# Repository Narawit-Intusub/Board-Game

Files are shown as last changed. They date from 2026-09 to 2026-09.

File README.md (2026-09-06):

# Modular Smart LED Matrix (กระดานไฟ LED อัจฉริยะต่อขยายได้อิสระสำหรับระบบเกมกระดาน)

---

## 1. ภาพรวมโปรเจกต์ (Project Overview)

**Modular Smart LED Matrix** คือ กระดานแสดงผลไฟ LED อัจฉริยะแบบต่อขยายได้อิสระ (Modular Interactive Tabletop Gaming Grid) ออกแบบมาเพื่อเป็นกระดานเล่นเกมแบบ Interactive ร่วมกับเอนจินเกม (เช่น Unity หรือ PC) และหน้าจอแสดงผลกราฟิกแบบปรับเปลี่ยนรูปทรงได้อย่างอิสระ

ระบบถูกออกแบบภายใต้สถาปัตยกรรม **Smart Tile (Distributed Grid Architecture)** โดยแต่ละแผ่นกระดานมีขนาด **$192.0 \times 192.0\text{ mm}$ ($19.2 \times 19.2\text{ cm}$)** แบ่งเป็น **16 ช่องตาราง ($4 \times 4$ Cells ช่องละ $48.0 \times 48.0\text{ mm}$)** แต่ละช่องมีไฟ 4 หลอด (รวม 64 หลอดต่อแผ่น) ขับแสดงผลเฉพาะในบอร์ดตัวเองอย่างอิสระ ไม่ต่อสายไฟ LED เป็นโซ่อนุกรมข้ามบอร์ด

```text
Unity / PC
    │
    │ USB DATA
    ▼
┌───────────────────────────────┐
│ MASTER                        │
│                               │
│ ESP32 Gateway                 │
│    │ Internal UART            │
│    ▼                          │
│ ATtiny1604 Tile Controller    │
│    ├── LED Matrix ของ Master  │
│    └── Magnetic Bus N/E/S     │
└───────────────┬───────────────┘
                │
        VBUS, TX, RX, GND
                │
       ┌────────┴────────┐
       ▼                 ▼
┌─────────────┐   ┌─────────────┐
│ Slave Tile  │   │ Slave Tile  │
│ ATtiny1604  │   │ ATtiny1604  │
└─────────────┘   └─────────────┘
```

---

## 2. โครงสร้างระบบ (System Structure)

ชุดต้นแบบประกอบด้วยกระดานทั้งหมด 4 แผ่น:

| บอร์ด | ตัวควบคุม | หน้าที่หลัก |
| :--- | :--- | :--- |
| **Master (1 แผ่น)** | **ESP32 Wemos D1 Mini + ATtiny1604** | • **ESP32:** เกตเวย์เชื่อม Unity ผ่าน USB, เก็บ Topology ทั้งระบบ, คำนวณ Global Grid, แยก Packet ตาม Tile ID, ตรวจสอบสถานะระบบ<br>• **ATtiny1604:** ควบคุม Tile ของ Master, ขับ 64 LEDs, จัดการ Magnetic Bus N/E/S |
| **Slave 1 (1 แผ่น)** | **ATtiny1604** | ขับ LED 64 ดวงในตัว, รับ-ส่งต่อ Packet, ตรวจจับเพื่อนบ้าน |
| **Slave 2 (1 แผ่น)** | **ATtiny1604** | ขับ LED 64 ดวงในตัว, รับ-ส่งต่อ Packet, ตรวจจับเพื่อนบ้าน |
| **Slave 3 (1 แผ่น)** | **ATtiny1604** | ขับ LED 64 ดวงในตัว, รับ-ส่งต่อ Packet, ตรวจจับเพื่อนบ้าน |

### สรุปรวมอุปกรณ์หลักของระบบ:
* **ESP32:** จำนวน 1 ตัว (อยู่บนบอร์ด Master เท่านั้น ทำหน้าที่ Gateway ระดับระบบ)
* **ATtiny1604:** จำนวน 4 ตัว (ประจำทุกแผ่น แผ่นละ 1 ตัว ทำหน้าที่ Tile Controller มาตรฐานเดียวกัน)
* **USB Data:** ต่อคอมพิวเตอร์เฉพาะบอร์ด Master เพียงจุดเดียว
* **Power Input:** จ่ายไฟเข้าที่บอร์ด Master เพียงจุดเดียว แล้วส่งผ่านบัส `VBUS` ไปยังแต่ละแผ่น

---

## 3. หน้าที่ของแต่ละตัวควบคุม

### 3.1 หน้าที่ของ ESP32 (System Gateway)
* ติดต่อกับ Unity ผ่านสาย USB เพียงเส้นเดียว
* รับสถานะเกม ข้อมูลสีพิกัด และคำสั่งเฟรมภาพ
* บันทึกและวิเคราะห์โครงสร้างแผนผังทั้งหมดของระบบ (System Topology)
* คำนวณตำแหน่งสัมพัทธ์และการหมุนของแต่ละ Tile รวมเป็น Global Grid ผืนเดียว
* แยกข้อมูล Packet ตาม Tile ID
* ตรวจสอบสถานะและรายงานความผิดปกติของระบบ
* **ส่ง Packet ทั้งหมดให้ ATtiny1604 ของ Master ผ่าน Internal UART**
* *ESP32 ไม่ต้องต่อเข้าหัวแม่เหล็กภายนอกโดยตรง และไม่ต้องขับ LED โดยตรง*

### 3.2 หน้าที่ของ ATtiny1604 (Tile Controller ประจำทุกแผ่น รวม 4 ตัว)
* มีรหัส **Tile ID** ประจำตัว
* ขับไฟ LED ภายในแผ่นตัวเอง (64 LEDs จากข้อมูลสี 16 ช่อง)
* จัดการหน่วยความจำสี 16 ช่อง (Active Buffer และ Back Buffer)
* รับและส่งต่อ Packet ข้อมูลตามเส้นทางเครือข่าย
* ส่งข้อความ `HELLO` เพื่อค้นหาเพื่อนบ้าน
* **ตรวจจับเพื่อนบ้านและทิศทางการเชื่อมต่อเมื่อได้รับข้อความ `HELLO` ทางขา RX แยกแต่ละทิศ (`LINK_RX_N/E/S/W`)**
* รอรับสัญญาณแสดงผลพร้อมกัน (`FRAME_COMMIT`)
* รายงานสถานะกลับไปยัง ESP32 ผ่านโครงข่ายบัส
* **ATtiny บน Master และ Slave ใช้ Firmware สถาปัตยกรรมพื้นฐานชุดเดียวกัน**

---

## 4. บัสแม่เหล็ก 4 จุด (4-Pin Magnetic Link)

แต่ละขอบที่เชื่อมต่อระหว่างบอร์ดมีพินสัญญาณ 4 พิน:

$$\text{[ VBUS ]} \quad \vert \quad \text{[ LINK_TX ]} \quad \vert \quad \text{[ LINK_RX ]} \quad \vert \quad \text{[ GND ]}$$

```text
  Female Connector (North / East)       Male Connector (South / West)
      +---------------------+               +---------------------+
      | (1)  (2)  (3)  (4)  |               | (1)  (2)  (3)  (4)  |
      | VBUS LinkTX LinkRX GND|             | GND LinkTX LinkRX VBUS|
      +---------------------+               +---------------------+
```

### 4.1 การจับคู่เมื่อประกบบอร์ด (Poka-Yoke 180° Inversion):
เมื่อนำขอบ Female ประกบกับขอบ Male หลังหมุน 180° พินจะจับคู่ตรงกันอย่างถูกต้อง:
* $\text{Pin 1 (VBUS)} \longleftrightarrow \text{Pin 4 (VBUS)}$: บัสไฟเลี้ยงหลัก
* $\text{Pin 2 (LINK_TX)} \longleftrightarrow \text{Pin 3 (LINK_RX)}$: สายส่งข้อมูลชนสายรับข้อมูล
* $\text{Pin 3 (LINK_RX)} \longleftrightarrow \text{Pin 2 (LINK_TX)}$: สายรับข้อมูลชนสายส่งข้อมูล
* $\text{Pin 4 (GND)} \longleftrightarrow \text{Pin 1 (GND)}$: ระนาบกราวด์ร่วม

### 4.2 ทิศทางขั้วต่อในแต่ละบอร์ด:
* **Master มี 3 ทิศ:** **North, East, South** (เว้นด้าน **West** ไว้สำหรับช่องรับไฟหลักและพอร์ต USB สื่อสารกับคอมพิวเตอร์)
* **Slave มีครบ 4 ทิศ:** **North, East, South, West**

### 4.3 สถาปัตยกรรมการรับ-ส่งสัญญาณ (Directional RX & Shared TX):
บนแต่ละ Tile:
* มีขา **LINK_RX แยกอิสระ 4 ทิศทาง:** `LINK_RX_N`, `LINK_RX_E`, `LINK_RX_S`, `LINK_RX_W` ทำให้ระบุทิศทางของแพ็กเก็ตที่ส่งเข้ามาได้อย่างแม่นยำ
* มีขา **LINK_TX หนึ่งเส้นใช้ร่วมกันทุกด้าน:** เมื่อ Tile สั่งส่งข้อมูล ข้อมูลจะบรอดคาสต์ออกไปยังเพื่อนบ้านทุกด้านพร้อมกัน

---

## 5. รูปแบบแพ็กเก็ตและการป้องกันข้อมูลวนซ้ำ (Packet Architecture & Loop Prevention)

เนื่องจากขา `LINK_TX` เป็นสายร่วมที่กระจายสัญญาณออกทุกด้านพร้อมกัน Packet จึงต้องมีโครงสร้างข้อมูลกำกับ:

```text
+-----------+----------------+-----------------+--------------+-----+-----+--------+
| Source ID | Destination ID | Sequence Number | Frame Number | TTL | CRC | Data.. |
+-----------+----------------+-----------------+--------------+-----+-----+--------+
```

* **Source ID / Destination ID:** ระบุโหนดต้นทางและปลายทาง (หรือ Broadcast ID)
* **Sequence Number:** ลำดับของแพ็กเก็ต
* **Frame Number:** เลขเฟรมภาพสำหรับการซิงก์แสดงผล
* **TTL (Time-To-Live):** ลดค่าลงทีละ 1 ทุกครั้งที่ส่งต่อ เพื่อตัดวงจรแพ็กเก็ตตกค้าง
* **CRC:** ตรวจสอบความถูกต้องของข้อมูล
* **การป้องกันข้อมูลวนซ้ำ (Deduplication):** แต่ละ Tile จะจดจำ Sequence Number ล่าสุด และ**ไม่ประมวลผลแพ็กเก็ตเดิมซ้ำ** ช่วยป้องกันปัญหาข้อมูลวนลูปในกรณีที่มีเส้นทางเชื่อมต่อหลายทาง

---

## 6. เส้นทางข้อมูลที่ถูกต้อง (Data Flow Pipeline)

```text
Unity
  └──► ESP32 (Master)
         └──► ATtiny1604 (Master)
                ├──► ขับไฟ LED 64 ดวงบน Master
                └──► Magnetic Link (LINK_TX)
                       └──► ATtiny1604 (Slave Tile)
                              ├──► ขับไฟ LED 64 ดวงบน Slave
                              └──► ส่งต่อไปยัง Slave ถัดไป
```

* **Master Tile:** Unity $\rightarrow$ ESP32 $\rightarrow$ ATtiny Master $\rightarrow$ LED Master
* **Slave Tiles:** Unity $\rightarrow$ ESP32 $\rightarrow$ ATtiny Master $\rightarrow$ Magnetic Link $\rightarrow$ ATtiny Slave $\rightarrow$ ส่งต่อไปยัง Slave ถัดไป
* **ESP32 ไม่ส่งข้าม ATtiny Master ไปยังบอร์ดลูกโดยตรง**

---

## 7. สถาปัตยกรรมระบบไฟ (Power Architecture)

หลักการจ่ายไฟของระบบกำหนดไว้ดังนี้:

```text
Power Input
   └──► Master Protection
          └──► VBUS (ส่งผ่านขั้วต่อแม่เหล็กไปยังทุกแผ่น)
                 └──► Local Power Converter ในแต่ละ Tile
                        └──► 5V คงที่สำหรับขับ LED และเลี้ยง ATtiny1604
```

> [!IMPORTANT]
> **ข้อกำหนดในการออกแบบภาคจ่ายไฟ:**
> 1. **ใช้ชื่อบัสกลางว่า `VBUS`:** ไม่ส่งตรง 5V ผ่านทุกบอร์ดในระยะยาว เพื่อรองรับการจ่ายแรงดันที่สูงขึ้น (เช่น 9V–12V) แล้วใช้ Local Step-Down Converter ลดเป็น 5V ภายในแต่ละแผ่น เพื่อลดแรงดันตกคร่อม (Voltage Drop) และลดกระแสบนพินแม่เหล็ก
> 2. **ยังไม่ล็อกเบอร์อุปกรณ์และแรงดัน VBUS ในสเปกหลัก:** รายละเอียดของแรงดัน VBUS, ชนิดคอนเนคเตอร์ไฟเข้า, ชนิดวงจรแปลงไฟ, อุปกรณ์วัดกระแส, และพิกัด TVS (ห้ามล็อก SMAJ5.0A หาก VBUS มีโอกาสสูงกว่า 5V) จะสรุปหลังจากการทดสอบพิกัดกระแสจริงของหัวแม่เหล็กและกำลังวัตต์สูงสุดของ LED ทั้งระบบ
> 3. **ตัวต้านทาน CC 5.1kΩ:** ทำหน้าที่ระบุสถานะ Sink บนพอร์ต USB Type-C พื้นฐานเท่านั้น ไม่ได้รับรองการจ่ายกระแส 5V/3A และไม่ใช่ระบบเจรจาแรงดัน USB-PD

---

## 8. การจัดการระดับแรงดันสัญญาณ (Logic Level Translation)

* **หาก ATtiny1604 เลี้ยงด้วยไฟ 5V:** สัญญาณ GPIO เอาต์พุต (รวมถึงขาขับ LED `LED_DATA`) จะมีระดับแรงดันเป็น 5V CMOS Logic อยู่แล้ว จึงสามารถขับขา DIN ของโมดูล WS2812B ได้โดยตรงโดยไม่ต้องใช้ Level Shifter 3.3V$\rightarrow$5V หน้า LED
* **จุดที่ต้องแปลงระดับแรงดัน (Level Shifting):** คือส่วนเชื่อมต่อระหว่าง **ESP32 (แรงดันสัญญาณ 3.3V)** กับ **ATtiny1604 (แรงดันสัญญาณ 5V)** บนบอร์ด Master เพื่อให้การส่งข้อมูล UART ภายในทำงานได้อย่างถูกต้องและปลอดภัย

---

## 9. เอกสารอ้างอิงเฉพาะบอร์ด (Detailed Documentation Links)

* 📖 **[เอกสารวงจรและฮาร์ดแวร์บอร์ดแม่ (Master Controller Board README)](hardware/master/README.md)**
* 📖 **[เอกสารวงจรและฮาร์ดแวร์บอร์ดลูก (Slave Expansion Board README)](hardware/slave/README.md)**

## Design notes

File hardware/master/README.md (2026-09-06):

# Master Controller Board (บอร์ดแม่) - Dual-MCU Smart Tile (ESP32 + ATtiny1604)

เอกสารนี้อธิบายรายละเอียดการออกแบบทางฮาร์ดแวร์ บล็อกการทำงาน หน้าที่ของแต่ละโมดูล และโครงสร้างทางวิศวกรรมของ **Master Controller Board** (ไฟล์ KiCad: [Master_Matrix_4x4.kicad_sch](Master_Matrix_4x4.kicad_sch), [Master_Matrix_4x4.kicad_pcb](Master_Matrix_4x4.kicad_pcb)) ภายใต้สถาปัตยกรรม **Dual-MCU Smart Tile Grid**

---

## 1. ภาพรวมบอร์ดแม่ (Master Board Overview)

**Master Controller Board** ขนาดแผ่น **$192.0 \times 192.0\text{ mm}$ ($19.2 \times 19.2\text{ cm}$)** แบ่งเป็น **16 ช่องตาราง ($4 \times 4$ Cells ช่องละ $48.0 \times 48.0\text{ mm}$)** แต่ละช่องติดตั้งไฟ LED 4 ดวงแบบ $2 \times 2$ (รวม 64 หลอด) ทำหน้าที่เป็นทั้ง **พื้นที่เล่นในตัว** และ **เกตเวย์เชื่อมต่อกับคอมพิวเตอร์/Unity**

### สถาปัตยกรรมชิปคู่บนบอร์ดแม่ (Dual-MCU Architecture):
บอร์ดแม่รวมไมโครคอนโทรลเลอร์ 2 ตัวไว้บนแผ่นเดียว เพื่อแยกบทบาทหน้าที่อย่างชัดเจน:

1. **ESP32 Gateway (`U1`):**
   - เชื่อมต่อกับ Unity / PC ผ่านสาย USB ทางขอบด้านซ้าย (West)
   - รับข้อมูลเกม, สถานะ, ข้อมูลสี และค่าความสว่างจาก Unity
   - เก็บโครงสร้างแผนผังความสัมพันธ์ทั้งระบบ (System Topology Map)
   - คำนวณ Global Grid และแปลงพิกัดสากล
   - แยกข้อมูล Packet ตาม Tile ID
   - ตรวจสอบสถานะการทำงานของระบบ
   - **ส่งทุก Packet ให้ ATtiny1604 ของบอร์ดแม่ผ่าน Internal UART**
   - *ESP32 ไม่ต่อเข้าหัวแม่เหล็กภายนอกโดยตรง และไม่ขับ LED โดยตรง*

2. **ATtiny1604 Master Tile Controller (`U_ATTINY`):**
   - ทำหน้าที่เป็น Smart Tile ประจำบอร์ดแม่ โดยใช้ **Firmware สถาปัตยกรรมเดียวกับบอร์ดลูก**
   - รับ Packet ข้อมูลจาก ESP32
   - จัดการเก็บสี 16 ช่องในหน่วยความจำ (Active Buffer และ Back Buffer)
   - ขับไฟ LED 64 ดวงในบอร์ดตัวเอง (1 สี ขยายออกเป็น 4 หลอดต่อช่อง)
   - ขับสัญญาณออกสู่โครงข่ายแม่เหล็ก 3 ทิศทาง (**North, East, South**) ผ่านสาย `LINK_TX`
   - กระจายสัญญาณและส่งต่อแพ็กเก็ตไปยังบอร์ดลูก

```text
Unity Game Engine
       │ USB DATA
       ▼
+-------------------------------------------------------------------------+
|                        Master Controller Board                          |
|                                                                         |
|                     [ J_NORTH (Female Mag-4P) ]                         |
|                     (VBUS, Link TX, Link RX, GND)                       |
|                                  ^                                      |
|                                  |                                      |
|  [ POWER INPUT ]            +----+----+                                 |
|  [ USB TO UNITY ]           | ATtiny  | <---> [ J_EAST (Female) ]       |
|         │                   |  1604   |       (VBUS, TX, RX, GND)       |
|         ▼                   | Master  |                                 |
|   +-----------+  Internal   +----+----+                                 |
|   |   ESP32   |  UART            | DIN_LOCAL (5V Logic)                 |
|   |  Gateway  | ---------->      v                                      |
|   +-----------+ (Level Shift)+---------------+                          |
|         │                    |  LED Matrix   | (MOD1 -> MOD2 -> .. MOD16|
|  (System Mgmt)               |  (64 LEDs)    | (Local Driving Only)     |
|   (West Edge)                +---------------+                          |
|                                  |                                      |
|                                  v                                      |
|                     [ J_SOUTH (Male Mag-4P) ]                           |
|                     (VBUS, Link TX, Link RX, GND)                       |
+-------------------------------------------------------------------------+
```

---

## 2. ขั้วต่อแม่เหล็ก 3 ทิศทาง (3-Edge Magnetic Link Bus)

บอร์ด Master ติดตั้งขั้วต่อแม่เหล็กที่ขอบบอร์ด **3 ด้านเท่านั้น** ได้แก่ **North, East, South** (เว้นด้าน **West** ไว้สำหรับช่องรับไฟหลักและพอร์ต USB เชื่อมต่อคอมพิวเตอร์):

$$\text{Pin 1: [ VBUS ]} \quad \vert \quad \text{Pin 2: [ LINK_TX ]} \quad \vert \quad \text{Pin 3: [ LINK_RX ]} \quad \vert \quad \text{Pin 4: [ GND ]}$$

```text
  Female Connector (North / East)       Male Connector (South)
      +---------------------+               +---------------------+
      | (1)  (2)  (3)  (4)  |               | (1)  (2)  (3)  (4)  |
      | VBUS LinkTX LinkRX GND|             | GND LinkTX LinkRX VBUS|
      +---------------------+               +---------------------+
```

### การจับคู่สัญญาณเมื่อประกบกัน (Poka-Yoke 180° Inversion):
* **Pin 1 (VBUS) $\longleftrightarrow$ Pin 4 (VBUS):** บัสจ่ายไฟเลี้ยงหลักของโครงข่าย
* **Pin 2 (LINK_TX) $\longleftrightarrow$ Pin 3 (LINK_RX):** สายส่งข้อมูลชนสายรับข้อมูลของเพื่อนบ้าน
* **Pin 3 (LINK_RX) $\longleftrightarrow$ Pin 2 (LINK_TX):** สายรับข้อมูลชนสายส่งข้อมูลของเพื่อนบ้าน
* **Pin 4 (GND) $\longleftrightarrow$ Pin 1 (GND):** ระนาบกราวด์ร่วมของทั้งระบบ

---

## 3. เส้นทางข้อมูลและการกระจายสัญญาณ (Data Routing & Level Shifting)

1. **เส้นทางข้อมูล:**
   * Unity $\rightarrow$ ESP32 (ถอดรหัสและแยก Packet)
   * ESP32 $\rightarrow$ ATtiny Master (ผ่าน Internal UART)
   * ATtiny Master $\rightarrow$ ขับไฟ LED 64 ดวงบนบอร์ด Master
   * ATtiny Master $\rightarrow$ กระจายข้อมูลออกสู่ `LINK_TX` ขั้วต่อแม่เหล็ก N/E/S ไปยังบอร์ดลูก
2. **การแปลงระดับแรงดัน (Level Shifting):**
   * หาก ATtiny1604 ทำงานที่แรงดัน 5V เอาต์พุต GPIO ของ ATtiny จะเป็น 5V Logic อยู่แล้ว จึงขับขา DIN ของ WS2812B ได้โดยตรง
   * จุดที่ต้องแปลงระดับแรงดันคือระหว่าง **ESP32 (3.3V Logic)** กับ **ATtiny1604 (5V Logic)** บนสัญญาณ UART ภายใน เพื่อความเข้ากันได้ทางไฟฟ้าและความปลอดภัยของชิป
   * ทิศ ESP32 → ATtiny ใช้ `74AHCT1G125`; ทิศ ATtiny → ESP32 ใช้ตัวแบ่งแรงดัน 10kΩ/20kΩ เพื่อจำกัดสัญญาณประมาณ 3.3V
3. **Current monitor:** บัส I²C ของ INA219 มี pull-up 4.7kΩ ไปยัง `+3V3` แยกทั้ง SDA และ SCL

---

## 4. สถาปัตยกรรมระบบไฟ (Power Architecture)

หลักการจ่ายไฟของระบบ:
```text
Power Input
   └──► Master Protection
          └──► VBUS ผ่านขั้วต่อแม่เหล็ก
                 └──► Local Power Converter ในแต่ละ Tile
                        └──► 5V คงที่สำหรับขับ LED และเลี้ยง ATtiny1604
```

> [!NOTE]
> **การกำหนดสเปกภาคจ่ายไฟ:**
> * บัสส่งไฟระหว่างบอร์ดใช้ชื่อกลางว่า **`VBUS`** เพื่อรองรับการทดสอบแรงดันที่เหมาะสม (เช่น 5V ตรง หรือ 9V–12V ร่วมกับ Local Step-Down Converter) เพื่อลดปัญหากระแสสูงและแรงดันตกคร่อมบนพินแม่เหล็ก
> * สเปกของ Power Input, พิกัดแรงดัน VBUS, วงจรตรวจวัดกระแส, และเบอร์ไดโอด TVS จะถูกกำหนดอย่างเป็นทางการหลังทราบพิกัดกระแสจริงของหัวแม่เหล็กและกำลังวัตต์สูงสุดของ LED ทั้งระบบ (ไม่ล็อกเบอร์ SMAJ5.0A หาก VBUS ถูกปรับขึ้นสูงกว่า 5V)
> * ตัวต้านทาน CC 5.1kΩ บนพอร์ต Type-C ทำหน้าที่ระบุสถานะ Sink พื้นฐาน ไม่ได้รับรองการจ่าย 5V/3A และไม่ใช่ระบบ USB-PD
> * `R_BUS` เป็น **DNP โดยปริยาย** ห้ามประกอบเป็น 0Ω จนกว่าจะยืนยันว่าใช้ VBUS 5V แบบจำกัดกระแส หากต้องการขยายหลาย Tile ให้แทนตำแหน่งนี้ด้วย Local Power Converter ที่เลือกตามพิกัดจริง
> * ขา `VCC_(USB)` ของโมดูล ESP32 ไม่ผูกเข้ากับราง `+5V` ภายนอก เพื่อป้องกันการป้อนไฟย้อนเข้าสาย USB Data ของคอมพิวเตอร์

---

## 5. การส่งแพ็กเก็ตและตรวจจับเพื่อนบ้าน

* **การส่งข้อมูล (`LINK_TX`):** ATtiny Master ส่งออกทาง `LINK_TX` ซึ่งเชื่อมขนานไปยังขั้วต่อ N, E, S สัญญาณจะออกไปยังเพื่อนบ้านทุกด้านพร้อมกัน
* **การป้องกันข้อมูลวนซ้ำ (Deduplication):** Packet จะระบุ `Source ID`, `Destination ID`, `Sequence Number`, `Frame Number`, `TTL`, และ `CRC` ทุกโหนดจะไม่ประมวลผล Packet เดิมซ้ำ
* **การค้นหาเพื่อนบ้าน (Neighbor Discovery):** ขา `LINK_RX` แยกตามทิศทาง (`LINK_RX_N`, `LINK_RX_E`, `LINK_RX_S`) เมื่อได้รับข้อความ `HELLO` ทางขาใด จะทำให้ ATtiny ทราบทิศทางและบอร์ดที่เชื่อมต่ออยู่ทันที และส่งรายงานกลับไปยัง ESP32

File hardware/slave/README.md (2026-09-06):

# Slave Expansion Board (บอร์ดลูก) - Autonomous Smart Tile (ATtiny1604)

เอกสารนี้อธิบายรายละเอียดการออกแบบทางฮาร์ดแวร์ บล็อกการทำงาน หน้าที่ของแต่ละโมดูล และสถาปัตยกรรมของ **Slave Expansion Board** (ไฟล์ KiCad: [Slave_Matrix_4x4.kicad_sch](Slave_Matrix_4x4.kicad_sch), [Slave_Matrix_4x4.kicad_pcb](Slave_Matrix_4x4.kicad_pcb)) ภายใต้สถาปัตยกรรม **Modular Magnetic Smart Tile Grid**

---

## 1. ภาพรวมบอร์ดลูก (Slave Board Overview)

**Slave Expansion Board** ขนาดแผ่น **$192.0 \times 192.0\text{ mm}$ ($19.2 \times 19.2\text{ cm}$)** แบ่งเป็น **16 ช่องตาราง ($4 \times 4$ Cells ช่องละ $48.0 \times 48.0\text{ mm}$)** แต่ละช่องติดตั้งไฟ LED 4 ดวงแบบ $2 \times 2$ (รวม 64 หลอด) ทำหน้าที่เป็นกระดานส่วนขยายอัจฉริยะ สามารถเชื่อมต่อกับ Master หรือ Slave แผ่นอื่นได้ทั้ง 4 ทิศทาง (เหนือ, ใต้, ออก, ตก)

```text
+-----------------------------------------------------------------------------------+
|                           Slave Expansion Board                                   |
|                                                                                   |
|                        [ J_NORTH (Female Mag-4P) ]                                |
|                        (VBUS, Link TX, Link RX, GND)                              |
|                                     |                                             |
|                                     v                                             |
|  [ J_WEST (Male) ]  <--->   +---------------+   <--->  [ J_EAST (Female) ]        |
|  (VBUS, TX, RX, GND)        |  ATtiny1604   |          (VBUS, TX, RX, GND)        |
|                             |  Tile Node    |                                     |
|                             +-------+-------+                                     |
|                                     | Tile ID, Dual Framebuffer, Packet Routing   |
|         +---------------+           v                                             |
|         |  Status LED   |           | DIN_LOCAL (5V Logic from ATtiny)            |
|         +---------------+           v                                             |
|                             +---------------+                                     |
|                             |  LED Matrix   | (MOD1 -> MOD2 -> ... MOD16)         |
|                             |  (64 LEDs)    | (Local Driving Only, 16 Cells)      |
|                             +---------------+                                     |
|                                     |                                             |
|                                     v                                             |
|                        [ J_SOUTH (Male Mag-4P) ]                                  |
|                        (VBUS, Link TX, Link RX, GND)                              |
+-----------------------------------------------------------------------------------+
```

---

## 2. คุณสมบัติและความสามารถหลัก (Smart Tile Capabilities)

1. **มี Tile ID ประจำตัว:** บันทึกรหัสบอร์ดเฉพาะตัวไว้ใน Internal Flash / EEPROM
2. **การตรวจจับเพื่อนบ้านทางทิศทาง (Directional Neighbor Discovery):**
   - มีขา **LINK_RX แยกอิสระ 4 ทิศทาง:** `LINK_RX_N`, `LINK_RX_E`, `LINK_RX_S`, `LINK_RX_W`
   - **รู้ทิศทางเมื่อได้รับข้อความ `HELLO`:** โหนดจะระบุตำแหน่งและทิศทางของเพื่อนบ้านได้อย่างแม่นยำจากขา RX ที่ได้รับแพ็กเก็ต `HELLO` (ไม่ใช่การตรวจจับจากการเสียบเพียงอย่างเดียว)
3. **การประหยัด RAM (16 สีหลัก $\rightarrow$ 64 LEDs):**
   - เก็บข้อมูลสีเฉพาะ **16 ช่องตารางเกม** ($16 \times 3 = 48\text{ bytes}$)
   - **Active Buffer:** 48 bytes (กำลังแสดงผล)
   - **Back Buffer:** 48 bytes (กำลังรับข้อมูลเฟรมใหม่)
   - **รวมใช้ RAM เพียง 96 bytes** จาก SRAM 1024 bytes ของ ATtiny1604
   - ขณะขับสัญญาณออกสู่ WS2812 ชิป ATtiny จะทำการ **ขยาย 1 สีไปยัง 4 หลอดในช่องนั้นโดยอัตโนมัติ**
4. **การแสดงผลพร้อมกัน 60 FPS (Hardware Synchronous Commit):**
   - เมื่อได้รับคำสั่ง `FRAME_COMMIT` ผ่านสาย Link ทุกแผ่นจะสลับ Back Buffer $\rightarrow$ Active Buffer และขับรีเฟรชไฟพร้อมกันในระดับไมโครวินาที
5. **การขับไฟภายในบอร์ดตัวเอง (5V Logic):**
   - หาก ATtiny1604 เลี้ยงด้วยไฟ 5V ขา GPIO จะส่งสัญญาณ 5V CMOS Logic ขับขา DIN ของ WS2812B ได้โดยตรง
   - ขา DOUT ของหลอดไฟตัวสุดท้าย (`MOD16`) ไม่ต่อออกไปยังคอนเนคเตอร์ภายนอก

---

## 3. ขั้วต่อแม่เหล็ก 4 จุด (4-Pin Magnetic Link)

ขั้วต่อแม่เหล็ก 4 ขา ออกแบบสลับเพศตามหลัก **Poka-Yoke 180° Inversion**:
* ขอบ **North** และ **East** ใช้ขั้วต่อ **ตัวเมีย (Female)**
* ขอบ **South** และ **West** ใช้ขั้วต่อ **ตัวผู้ (Male)**

$$\text{Pin 1: [ VBUS ]} \quad \vert \quad \text{Pin 2: [ LINK_TX ]} \quad \vert \quad \text{Pin 3: [ LINK_RX ]} \quad \vert \quad \text{Pin 4: [ GND ]}$$

```text
  Female Connector (North / East)       Male Connector (South / West)
      +---------------------+               +---------------------+
      | (1)  (2)  (3)  (4)  |               | (1)  (2)  (3)  (4)  |
      | VBUS LinkTX LinkRX GND|             | GND LinkTX LinkRX VBUS|
      +---------------------+               +---------------------+
```

### การจับคู่สัญญาณเมื่อประกบกัน:
* $\text{Pin 1 (VBUS)} \longleftrightarrow \text{Pin 4 (VBUS)}$: บัสจ่ายไฟหลักเชื่อมต่อถึงกัน
* $\text{Pin 2 (LINK_TX)} \longleftrightarrow \text{Pin 3 (LINK_RX)}$: สายส่งข้อมูลชนสายรับข้อมูล
* $\text{Pin 3 (LINK_RX)} \longleftrightarrow \text{Pin 2 (LINK_TX)}$: สายรับข้อมูลชนสายส่งข้อมูล
* $\text{Pin 4 (GND)} \longleftrightarrow \text{Pin 1 (GND)}$: ระนาบกราวด์ร่วมกัน

---

## 4. การกระจายแพ็กเก็ตและการป้องกันข้อมูลวนซ้ำ (Shared TX & Deduplication)

* **LINK_TX หนึ่งเส้นใช้ร่วมกันทุกด้าน:** เมื่อบอร์ด Slave ส่งแพ็กเก็ตออกทาง `LINK_TX` สัญญาณจะออกไปยังเพื่อนบ้านทุกด้านที่เชื่อมต่ออยู่พร้อมกัน
* **โครงสร้างแพ็กเก็ต:**
  ```text
  +-----------+----------------+-----------------+--------------+-----+-----+--------+
  | Source ID | Destination ID | Sequence Number | Frame Number | TTL | CRC | Data.. |
  +-----------+----------------+-----------------+--------------+-----+-----+--------+
  ```
* **การป้องกันลูป (Loop Prevention):** แต่ละ Tile จะบันทึก `Sequence Number` ล่าสุดของแต่ละโหนด หากได้รับ Packet เดิมซ้ำ จะเพิกเฉยทันที (Drop duplicate) ช่วยป้องกันปัญหาแพ็กเก็ตสะท้อนวนในโครงข่าย

---

## 5. สถาปัตยกรรมระบบไฟ (Power Architecture)

```text
VBUS (รับจากหัวแม่เหล็ก)
   └──► Local Protection
          └──► Local Power Converter
                 └──► 5V คงที่สำหรับขับ LED และเลี้ยง ATtiny1604
```

> [!NOTE]
> **หลักการภาคจ่ายไฟของบอร์ดลูก:**
> * รับไฟผ่านบัสกลาง **`VBUS`** โดยแรงดันและรูปแบบของ Local Power Converter จะถูกสรุปหลังทราบพิกัดกระแสจริงของหัวแม่เหล็กและกำลังวัตต์สูงสุดของ LED ทั้งระบบ
> * ไม่ล็อกเบอร์ TVS (เช่น SMAJ5.0A) ในสเปกหลัก เพื่อรองรับการปรับระดับแรงดัน VBUS ให้เหมาะสมกับการใช้งานจริง
> * `R_BUS` เป็น **DNP โดยปริยาย** ห้ามประกอบเป็น 0Ω จนกว่าจะยืนยันการใช้ VBUS 5V แบบจำกัดกระแส หากใช้บัสแรงดันสูงให้แทนด้วย Local Power Converter ที่มีพิกัดเหมาะกับ LED 64 ดวงต่อ Tile

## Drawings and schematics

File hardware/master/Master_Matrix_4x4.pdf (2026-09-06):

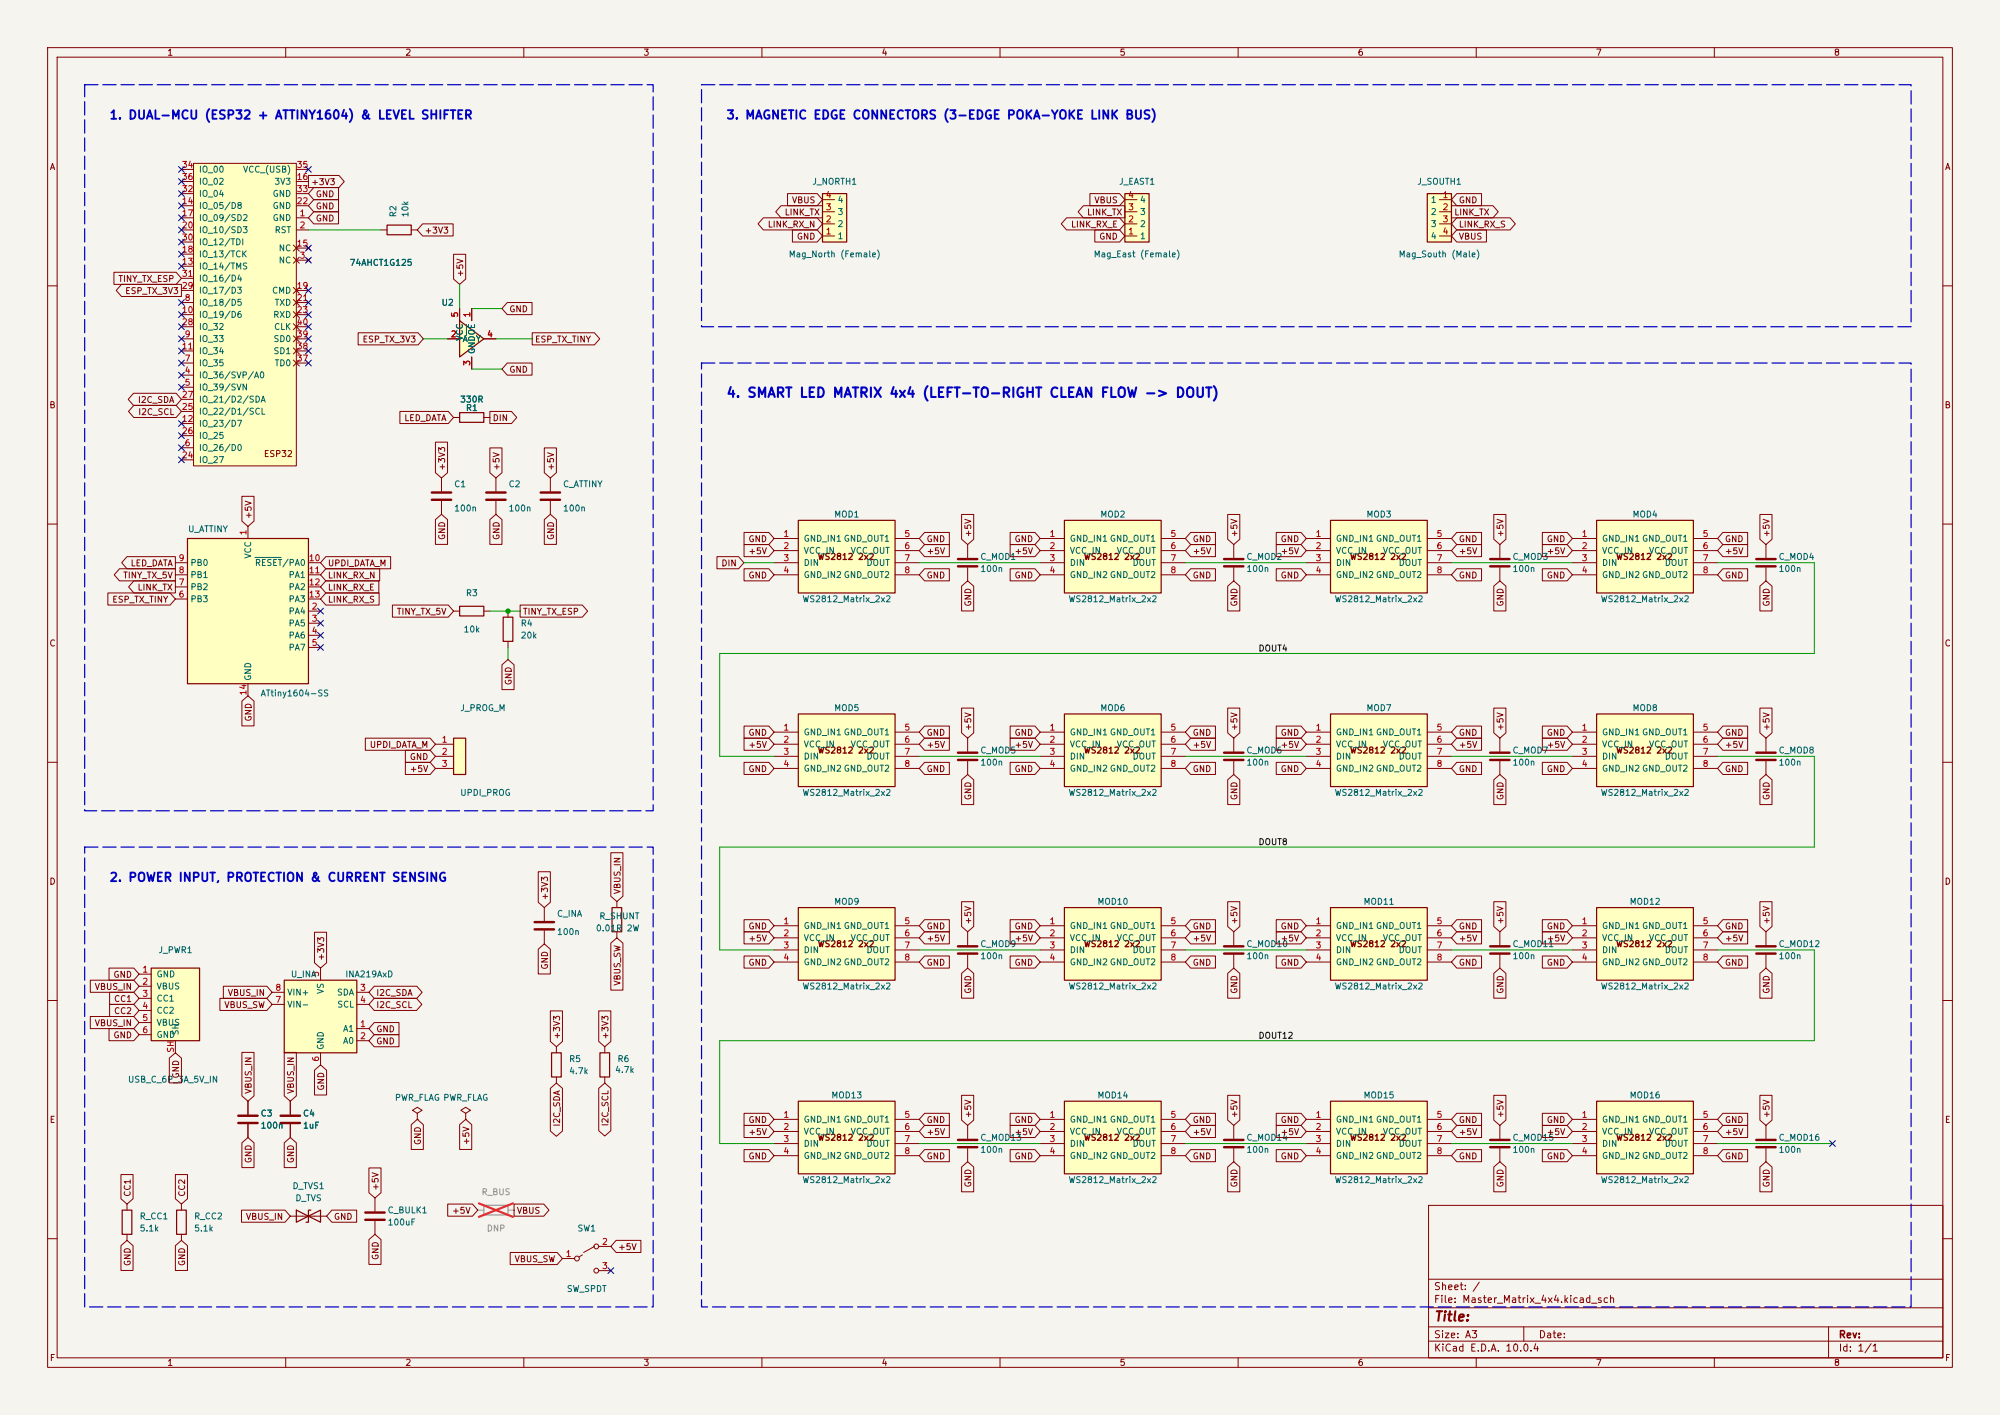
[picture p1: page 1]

1. DUAL-MCU (ESP32 + ATTINY1604) & LEVEL SHIFTER

3. MAGNETIC EDGE CONNECTORS (3-EDGE POKA-YOKE LINK BUS)

4. SMART LED MATRIX 4x4 (LEFT-TO-RIGHT CLEAN FLOW -> DOUT)

2. POWER INPUT, PROTECTION & CURRENT SENSING

Size: A3 | Rev: | F Date:
KiCad E.D.A. 10.0.4 | Id: 1/1

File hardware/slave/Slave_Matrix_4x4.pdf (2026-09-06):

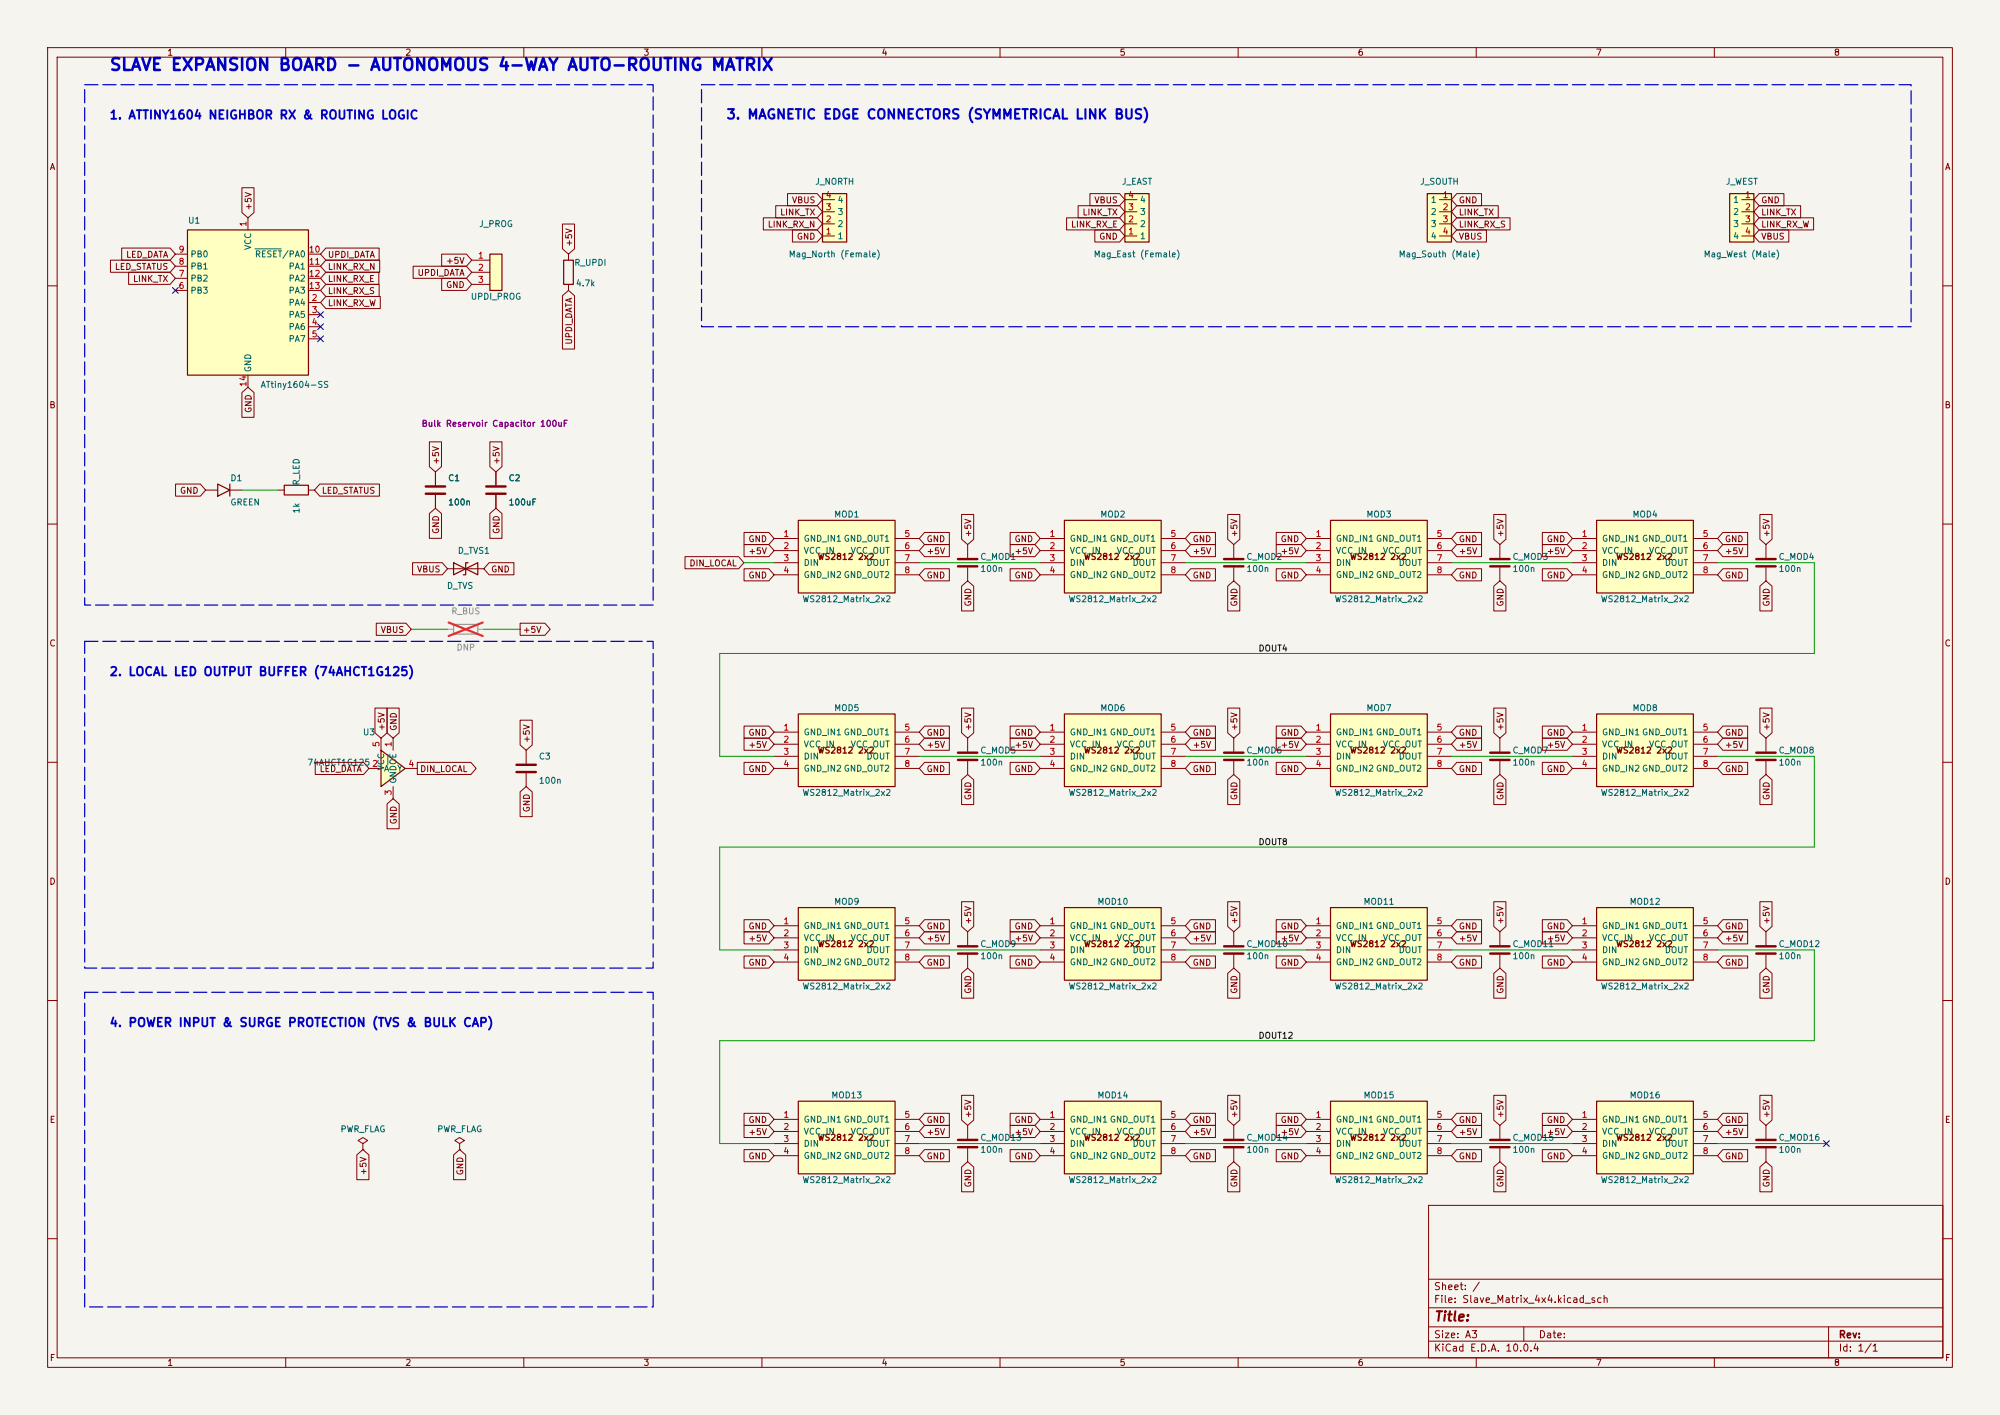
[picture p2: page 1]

SLAVE EXPANSION BOARD - AUTONOMOUS 4-WAY AUTO-ROUTING MATRIX

3. MAGNETIC EDGE CONNECTORS (SYMMETRICAL LINK BUS)

DOUT4 DOUT8 DOUT12 4. POWER INPUT & SURGE PROTECTION (TVS & BULK CAP)
2. LOCAL LED OUTPUT BUFFER (74AHCT1G125)

Size: A3 | Rev: | F Date:
KiCad E.D.A. 10.0.4 | Id: 1/1

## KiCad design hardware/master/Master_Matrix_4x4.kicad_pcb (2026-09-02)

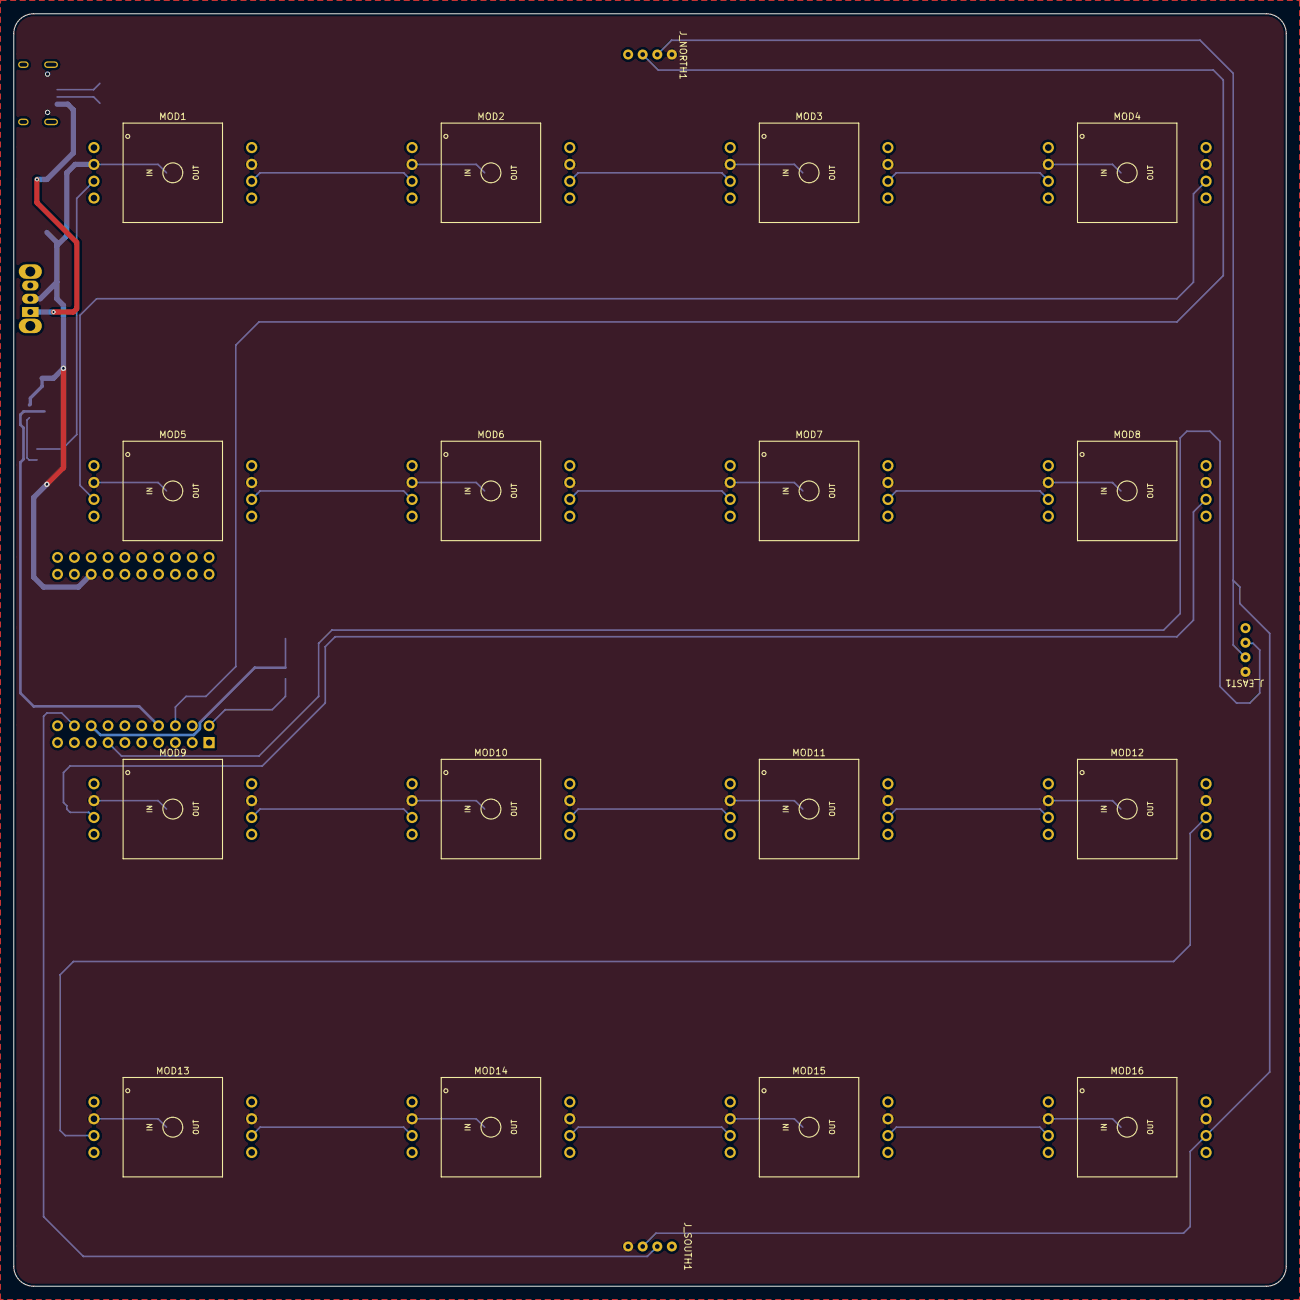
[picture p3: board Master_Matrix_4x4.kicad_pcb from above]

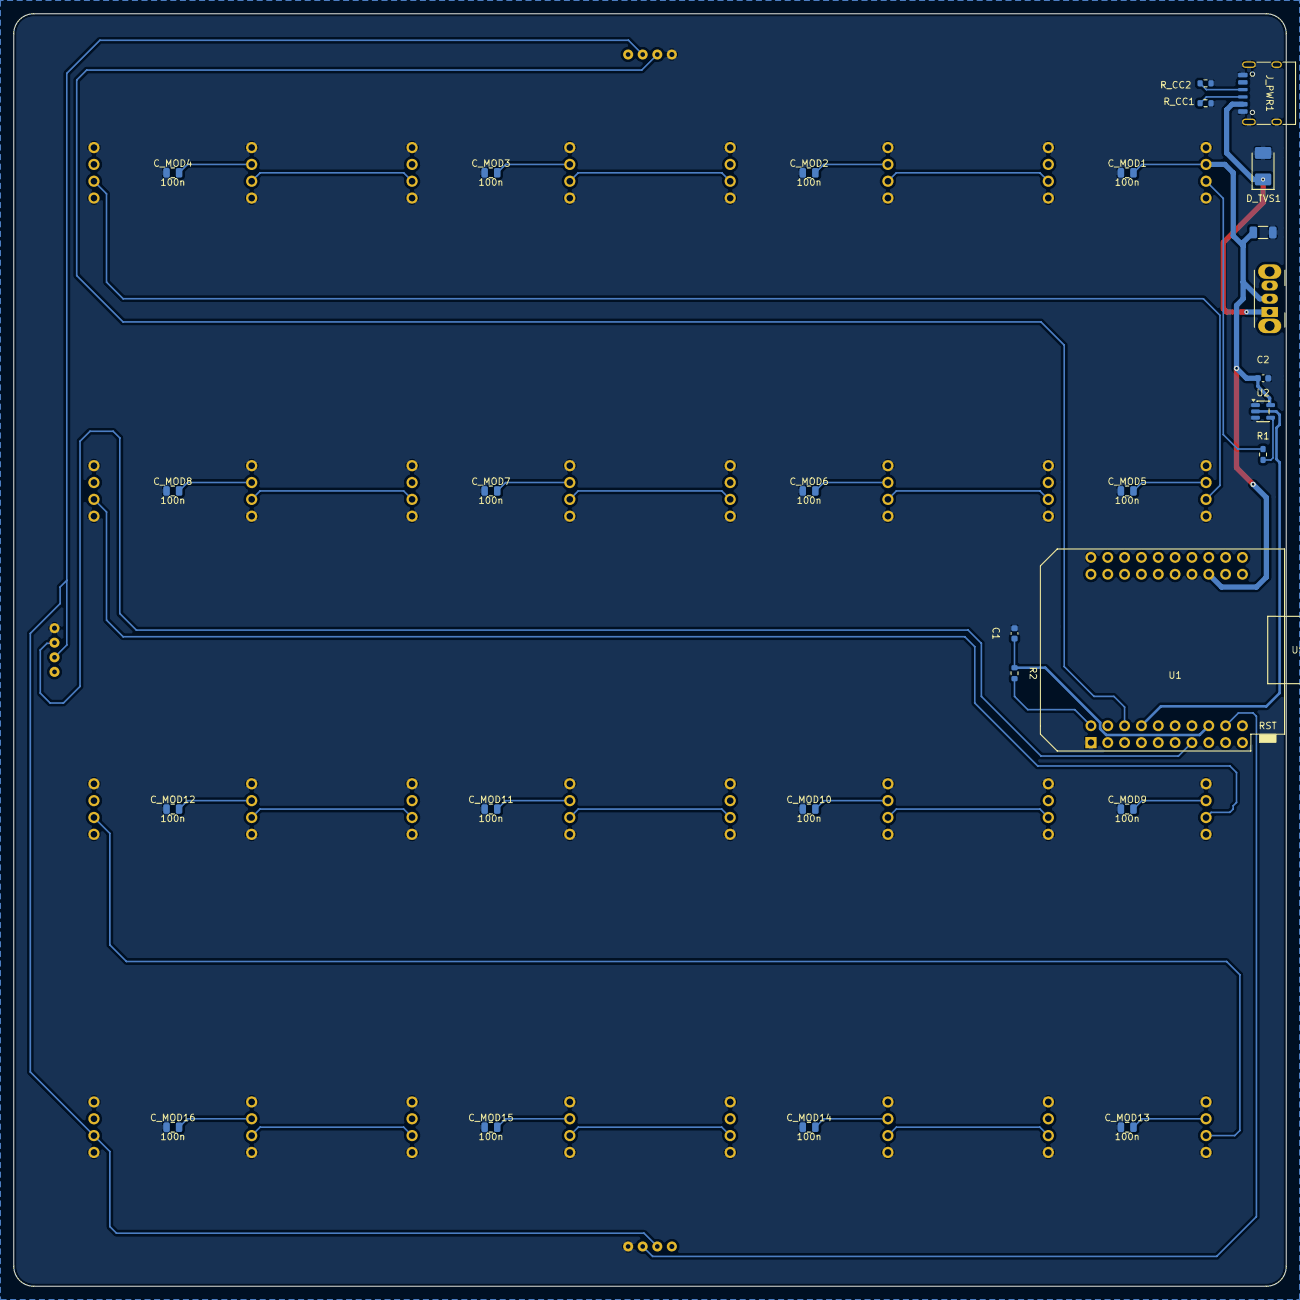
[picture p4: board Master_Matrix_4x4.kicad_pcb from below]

Board: 2 copper layers, 192.0 x 192.0 mm, 79 parts (28 on the bottom side), 29 nets.

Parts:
C1, C2: 100n; C_0603_1608Metric
C_BULK1: 100uF; C_1206_3216Metric
C_MOD1, C_MOD2, C_MOD3, C_MOD4, C_MOD5, C_MOD6, C_MOD7, C_MOD8, C_MOD9, C_MOD10, C_MOD11, C_MOD12, C_MOD13, C_MOD14, C_MOD15, C_MOD16: 100n; C_0805_2012Metric
D_TVS1: SMAJ5.0A; D_SMA
J_EAST1: Mag_East (Female); fakemag4pin90degFemale
J_IN1, J_IN2, J_IN3, J_IN4, J_IN5, J_IN6, J_IN7, J_IN8, J_IN9, J_IN10, J_IN11, J_IN12, J_IN13, J_IN14, J_IN15, J_IN16: PTH_4P_IN
J_NORTH1: Mag_North (Female); fakemag4pin90degFemale
J_OUT1, J_OUT2, J_OUT3, J_OUT4, J_OUT5, J_OUT6, J_OUT7, J_OUT8, J_OUT9, J_OUT10, J_OUT11, J_OUT12, J_OUT13, J_OUT14, J_OUT15, J_OUT16: PTH_4P_OUT
J_PWR1: USB_C_6P_3A_5V_IN; USB_C_Receptacle_6P_SMD
J_SOUTH1: Mag_South (Male); fakemag4pin90degMale
MOD1, MOD2, MOD3, MOD4, MOD5, MOD6, MOD7, MOD8, MOD9, MOD10, MOD11, MOD12, MOD13, MOD14, MOD15, MOD16: WS2812_Matrix_2x2; WS2812_Matrix_2x2_15x15mm
R1: 330R; R_0603_1608Metric
R2: 10k; R_0603_1608Metric
R_CC1, R_CC2: 5.1k; R_0603_1608Metric
SW1: SW_SPDT; SW_Slide_SPDT_Angled_CK_OS102011MA1Q
U1: esp32-wemos-d1-mini
U2: 74AHCT1G125; SOT-23-5

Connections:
+3V3: C1.1, R2.1, U1.16 (3V3)
+5V: C2.1, C_BULK1.1, C_MOD1.1, C_MOD2.1, C_MOD3.1, C_MOD4.1, C_MOD5.1, C_MOD6.1, C_MOD7.1, C_MOD8.1, C_MOD9.1, C_MOD10.1, C_MOD11.1, C_MOD12.1, C_MOD13.1, C_MOD14.1, C_MOD15.1, C_MOD16.1, J_EAST1.1 (VCC), J_IN1.2, J_IN2.2, J_IN3.2, J_IN4.2, J_IN5.2, J_IN6.2, J_IN7.2, J_IN8.2, J_IN9.2, J_IN10.2, J_IN11.2, J_IN12.2, J_IN13.2, J_IN14.2, J_IN15.2, J_IN16.2, J_NORTH1.1 (VCC), J_OUT1.2, J_OUT2.2, J_OUT3.2, J_OUT4.2, J_OUT5.2, J_OUT6.2, J_OUT7.2, J_OUT8.2, J_OUT9.2, J_OUT10.2, J_OUT11.2, J_OUT12.2, J_OUT13.2, J_OUT14.2, J_OUT15.2, J_OUT16.2, J_SOUTH1.1 (GND), SW1.2 (B), U1.35 (VCC_(USB)), U2.5 (VCC)
/DOUT4: J_IN5.3, J_OUT4.3
/DOUT8: J_IN9.3, J_OUT8.3
/DOUT12: J_IN13.3, J_OUT12.3
CC1: J_PWR1.3 (CC1), R_CC1.1
CC2: J_PWR1.4 (CC2), R_CC2.1
D01: J_NORTH1.3 (D1), U1.6 (IO_26/D0)
D11: J_EAST1.3 (D1), U1.13 (IO_14/TMS)
D21: J_SOUTH1.3 (D0), U1.18 (IO_13/TCK)
DIN: J_IN1.3, R1.2
DIN_3V3: U1.8 (IO_18/D5), U2.2 (A)
DOUT: J_EAST1.2 (D0), J_NORTH1.2 (D0), J_OUT16.3, J_SOUTH1.2 (D1)
GND: C1.2, C2.2, C_BULK1.2, C_MOD1.2, C_MOD2.2, C_MOD3.2, C_MOD4.2, C_MOD5.2, C_MOD6.2, C_MOD7.2, C_MOD8.2, C_MOD9.2, C_MOD10.2, C_MOD11.2, C_MOD12.2, C_MOD13.2, C_MOD14.2, C_MOD15.2, C_MOD16.2, D_TVS1.2 (A2), J_EAST1.4 (GND), J_IN1.1, J_IN1.4, J_IN2.1, J_IN2.4, J_IN3.1, J_IN3.4, J_IN4.1, J_IN4.4, J_IN5.1, J_IN5.4, J_IN6.1, J_IN6.4, J_IN7.1, J_IN7.4, J_IN8.1, J_IN8.4, J_IN9.1, J_IN9.4, J_IN10.1, J_IN10.4, J_IN11.1, J_IN11.4, J_IN12.1, J_IN12.4, J_IN13.1, J_IN13.4, J_IN14.1, J_IN14.4, J_IN15.1, J_IN15.4, J_IN16.1, J_IN16.4, J_NORTH1.4 (GND), J_OUT1.1, J_OUT1.4, J_OUT2.1, J_OUT2.4, J_OUT3.1, J_OUT3.4, J_OUT4.1, J_OUT4.4, J_OUT5.1, J_OUT5.4, J_OUT6.1, J_OUT6.4, J_OUT7.1, J_OUT7.4, J_OUT8.1, J_OUT8.4, J_OUT9.1, J_OUT9.4, J_OUT10.1, J_OUT10.4, J_OUT11.1, J_OUT11.4, J_OUT12.1, J_OUT12.4, J_OUT13.1, J_OUT13.4, J_OUT14.1, J_OUT14.4, J_OUT15.1, J_OUT15.4, J_OUT16.1, J_OUT16.4, J_PWR1.1 (GND), J_PWR1.6 (GND), J_PWR1.SH (SHIELD), J_SOUTH1.4 (VCC), R_CC1.2, R_CC2.2, U1.1 (GND), U1.22 (GND), U1.33 (GND), U2.1 (~OE), U2.3 (GND)
unnamed: J_IN2.3, J_OUT1.3
unnamed: J_IN3.3, J_OUT2.3
unnamed: J_IN4.3, J_OUT3.3
unnamed: J_IN6.3, J_OUT5.3
unnamed: J_IN7.3, J_OUT6.3
unnamed: J_IN8.3, J_OUT7.3
unnamed: J_IN10.3, J_OUT9.3
unnamed: J_IN11.3, J_OUT10.3
unnamed: J_IN12.3, J_OUT11.3
unnamed: J_IN14.3, J_OUT13.3
unnamed: J_IN15.3, J_OUT14.3
unnamed: J_IN16.3, J_OUT15.3
unnamed: R2.2, U1.2 (RST)
unnamed: R1.1, U2.4 (Y)
VBUS_IN: D_TVS1.1 (A1), J_PWR1.2 (VBUS), J_PWR1.5 (VBUS), SW1.1 (A)

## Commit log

2026-08-24 feat: initial commit for Modular Smart LED Matrix hardware and docs
    [Master_Matrix_4x4.kicad_sch, Slave_Matrix_4x4.kicad_sch]
2026-09-02 feat(hardware): update Master 4x4 schematic, export PDF, add PCB layout and libraries
    [Master_Matrix_4x4.kicad_pcb, Master_Matrix_4x4.kicad_sch, Slave_Matrix_4x4.kicad_sch]
2026-09-02 feat(hardware): update Master PCB layout and Master/Slave 4x4 matrix schematics
    [Master_Matrix_4x4.kicad_pcb, Master_Matrix_4x4.kicad_sch, Slave_Matrix_4x4.kicad_sch]
2026-09-02 docs(hardware): update Master 4x4 schematic PDF export
2026-09-02 docs(hardware): update Slave 4x4 schematic PDF export
2026-09-06 feat(hardware): update schematics, symbol libraries, and system architecture docs
    - Update Master and Slave 4x4 matrix schematics with proper data flow pipeline and symbol pinouts
    - Align symbol libraries (esp32-wemos-d1-mini, ws2812-matrix-2x2) across common and local folders
    - Update project README and hardware documentation for VBUS power distribution, level shifting, and data flow architecture
    [Master_Matrix_4x4.kicad_sch, Slave_Matrix_4x4.kicad_sch]
2026-09-06 docs(hardware): update Master and Slave 4x4 schematic PDF exports
